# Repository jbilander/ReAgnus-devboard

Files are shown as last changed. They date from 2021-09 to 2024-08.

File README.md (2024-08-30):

# ReAgnus-devboard
A development board for ReAgnus<br />

Compatible with the [PLCC-84-plug](https://github.com/jbilander/PLCC-84-plug)

With this board you can signal tap a real Agnus chip by having a real Agnus IC in one socket and ReAgnus in the other.

***

REV 1C

<a href="images/ReAgnus-devboard_pic1.jpg">
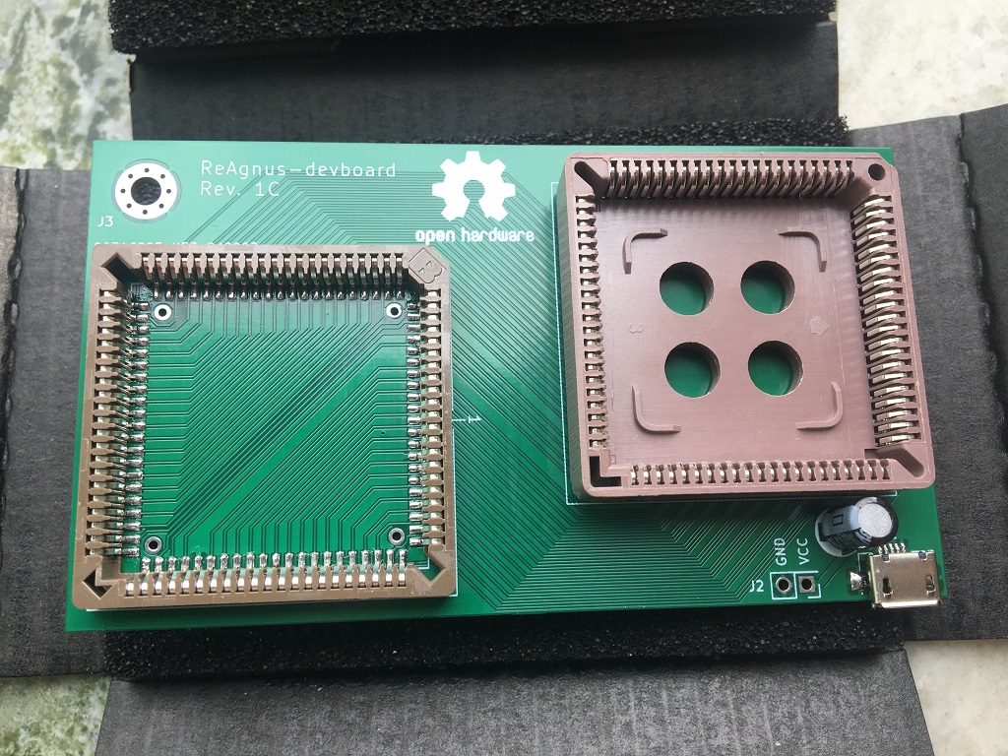
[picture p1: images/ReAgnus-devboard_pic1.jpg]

</a>
<br />
<a href="images/ReAgnus-devboard_pic2.jpg">
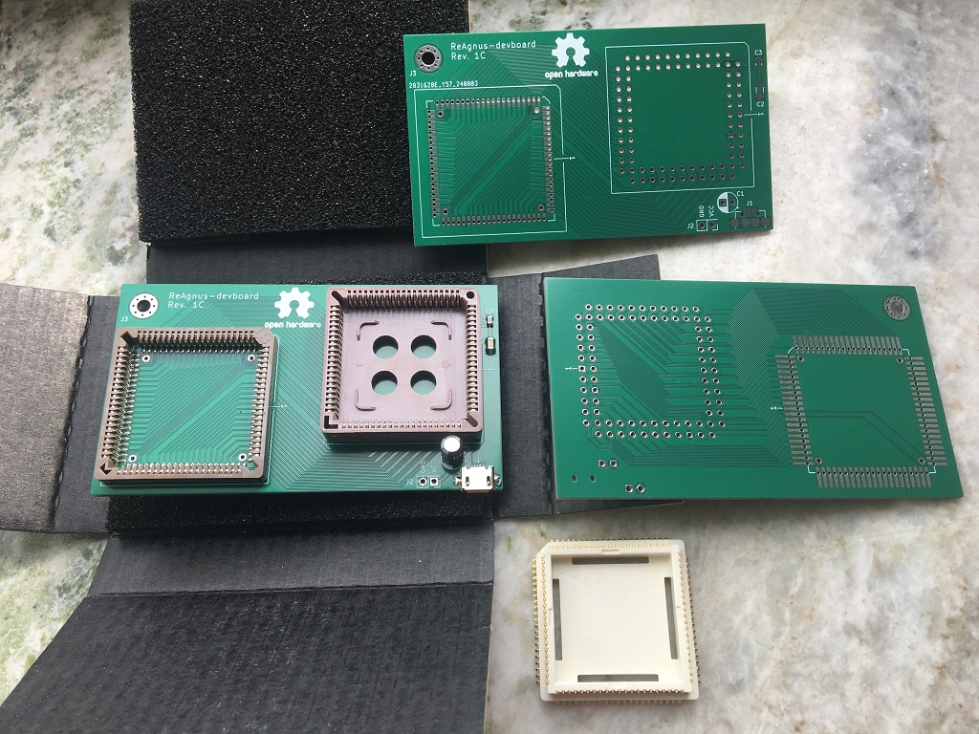
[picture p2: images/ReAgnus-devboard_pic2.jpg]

</a>
<br />
<a href="images/ReAgnus-devboard_pic3.jpg">
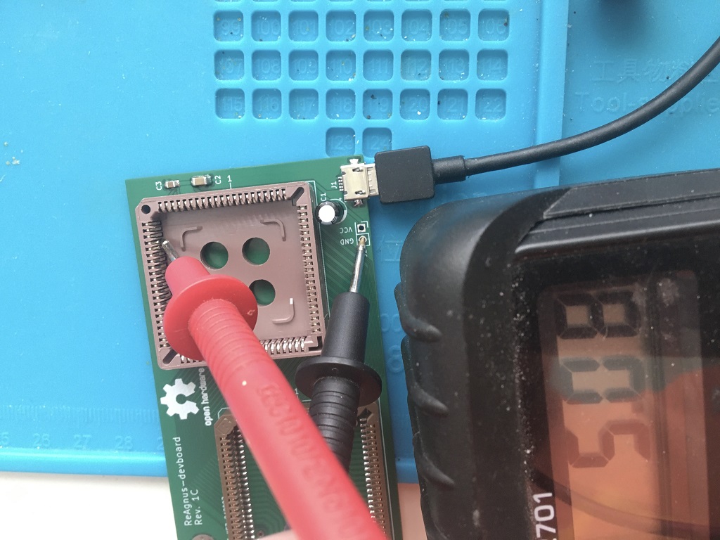
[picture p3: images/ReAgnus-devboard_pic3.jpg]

</a>
<br />
<a href="images/ReAgnus-devboard_pic4.jpg">
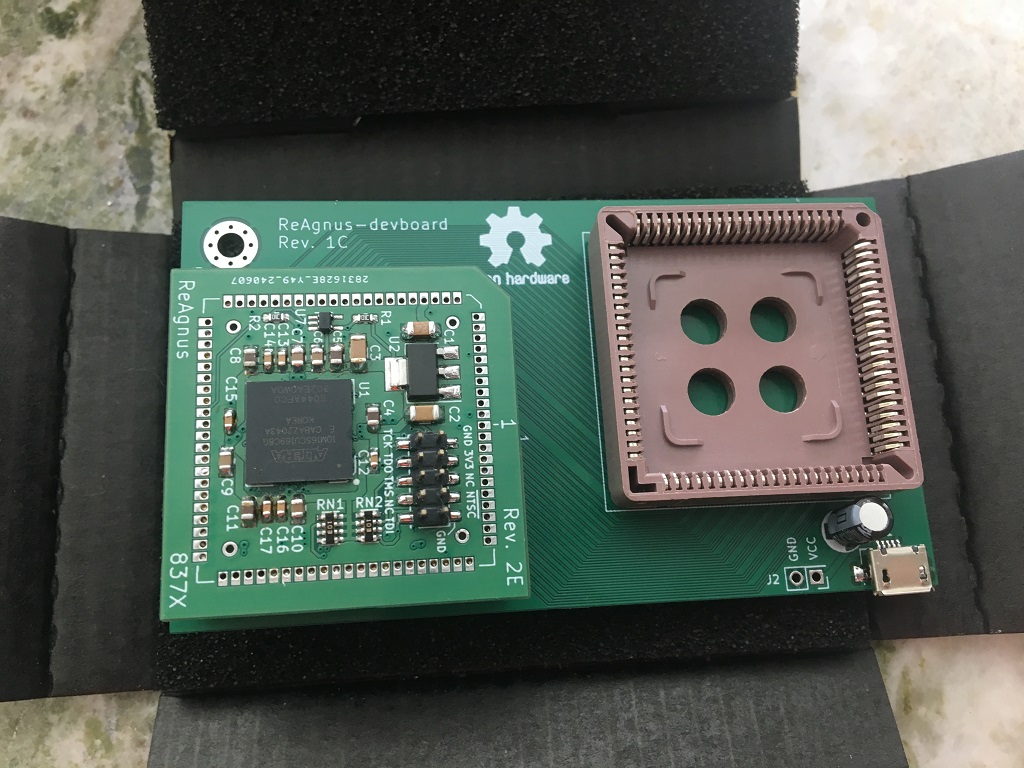
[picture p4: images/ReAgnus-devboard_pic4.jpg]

</a>
<br />
<a href="images/ReAgnus-devboard_pic5.jpg">
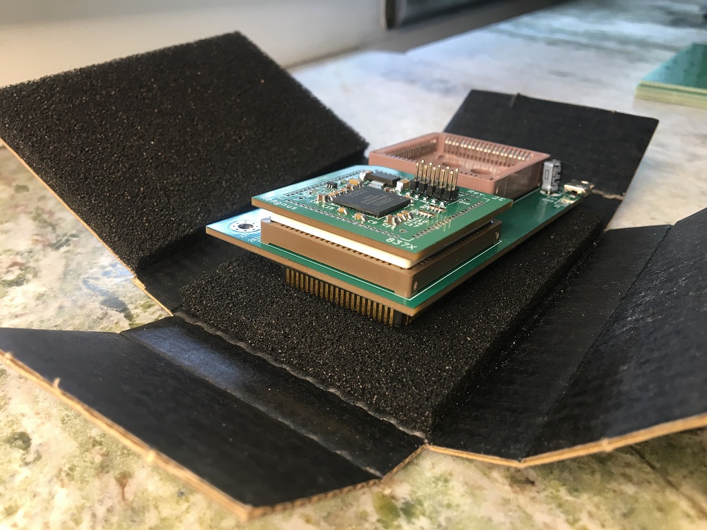
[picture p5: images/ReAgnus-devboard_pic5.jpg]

</a>

***

[][cc-by-sa]

This work is licensed under a
[Creative Commons Attribution-ShareAlike 4.0 International License][cc-by-sa].

[][cc-by-sa]

[cc-by-sa]: http://creativecommons.org/licenses/by-sa/4.0/
[cc-by-sa-image]: https://licensebuttons.net/l/by-sa/4.0/88x31.png
[cc-by-sa-shield]: https://img.shields.io/badge/License-CC%20BY--SA%204.0-lightgrey.svg

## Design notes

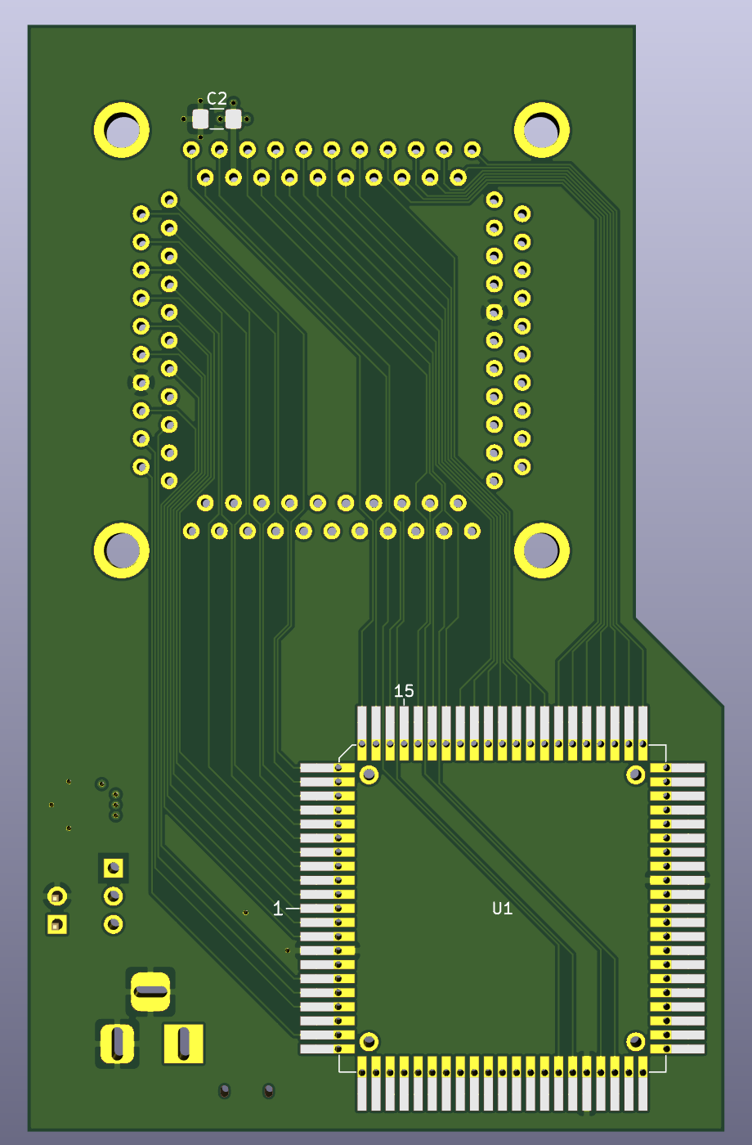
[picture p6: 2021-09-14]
images/ReAgnus-devboard_pic2.png

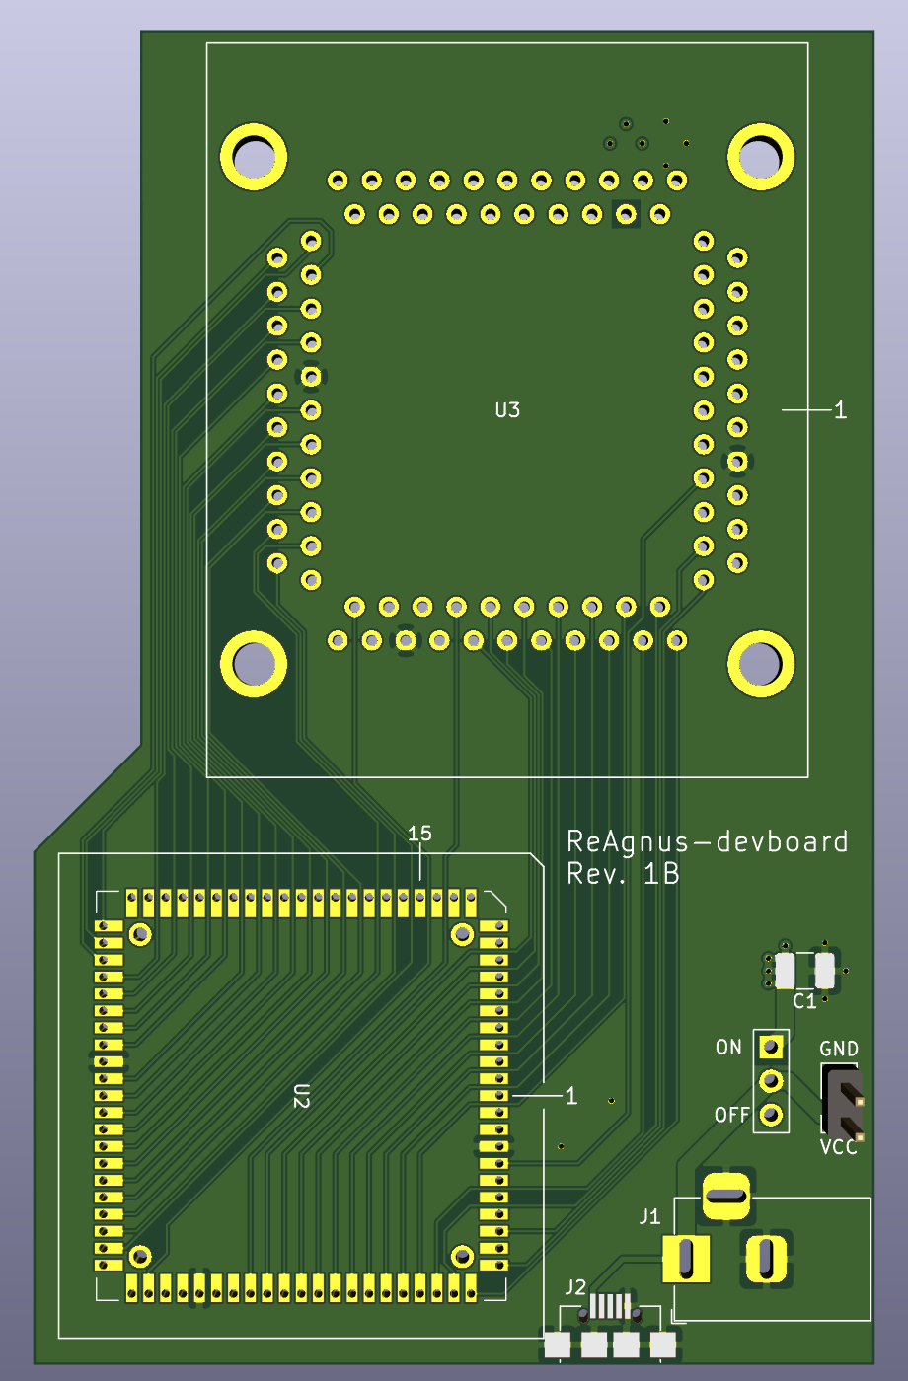
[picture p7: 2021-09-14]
images/ReAgnus-devboard_pic1.png

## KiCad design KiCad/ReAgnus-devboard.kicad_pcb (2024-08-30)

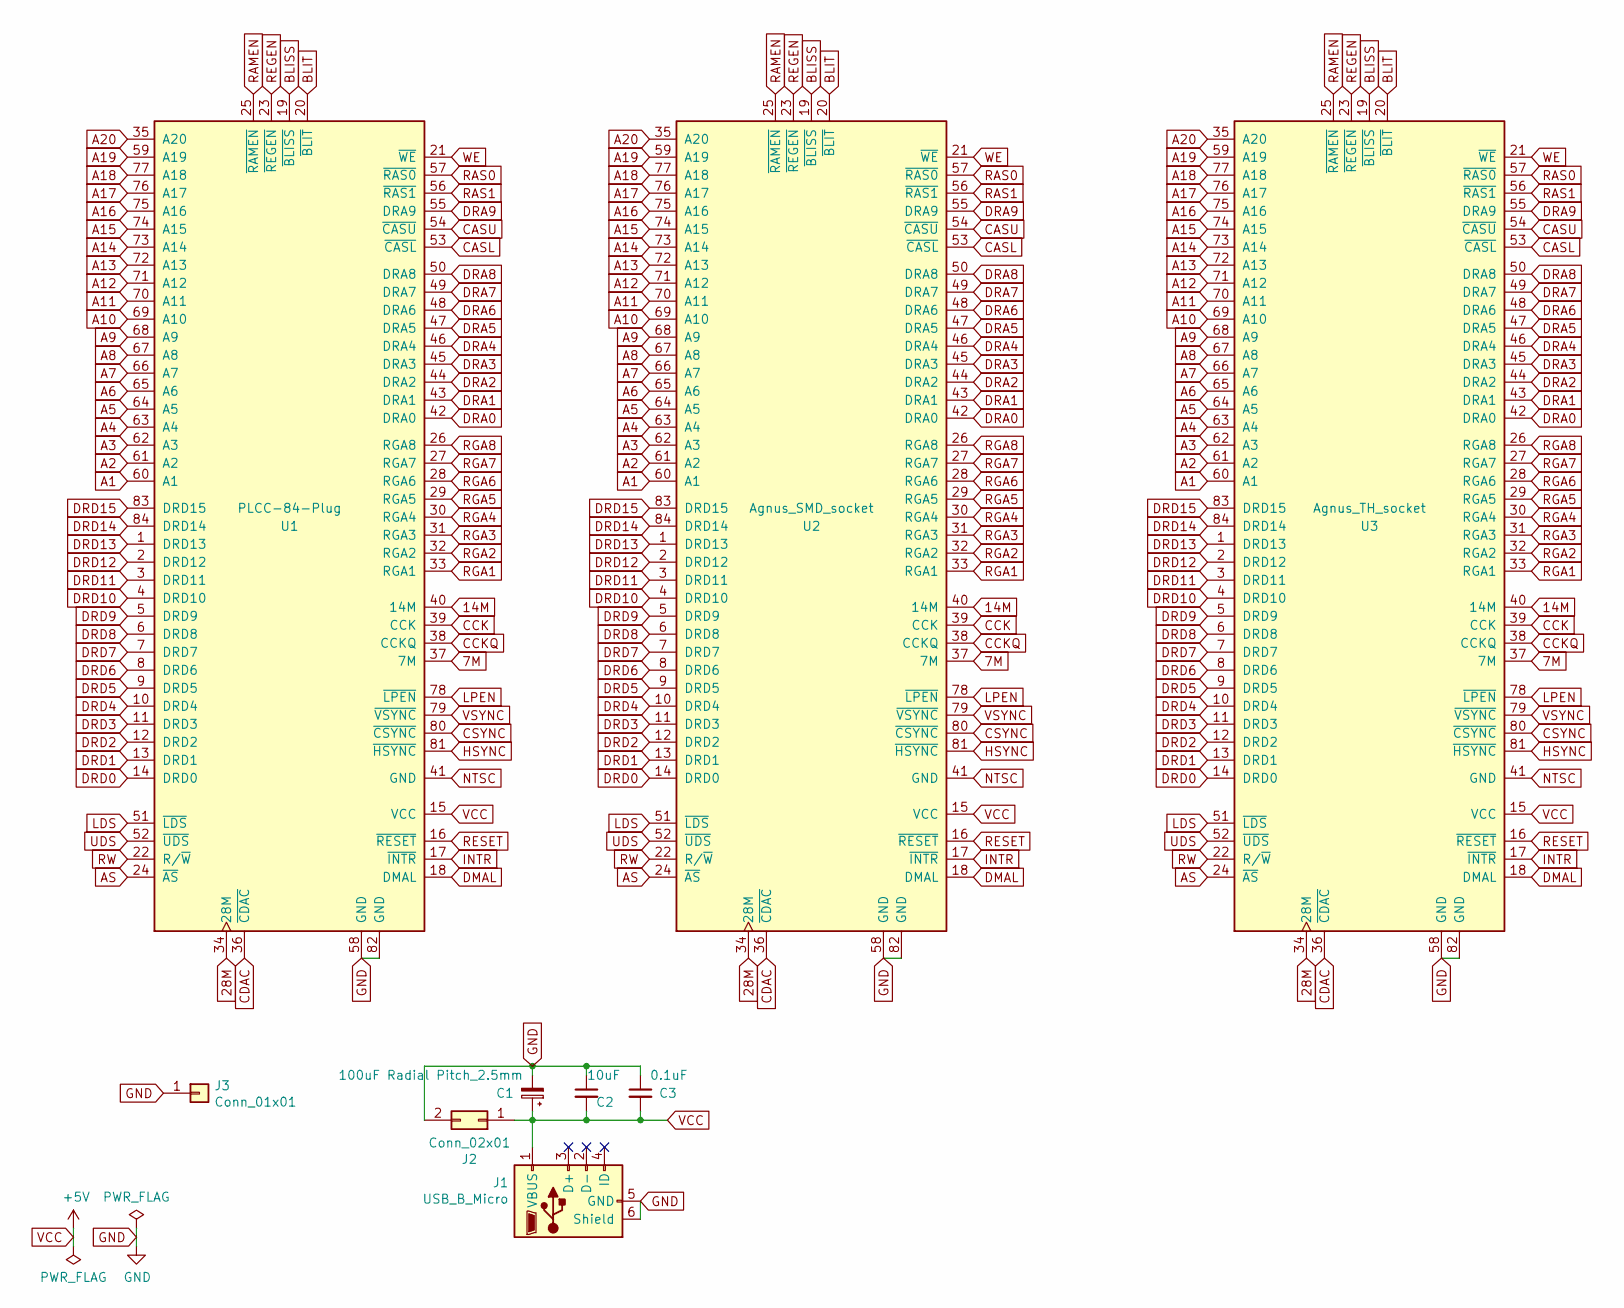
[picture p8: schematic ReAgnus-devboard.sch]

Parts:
C1: 100uF Radial Pitch_2.5mm; CP_Radial_D5.0mm_P2.50mm
C2: 10uF; C_1206_3216Metric_Pad1.33x1.80mm_HandSolder
C3: 0.1uF; C_0805_2012Metric_Pad1.18x1.45mm_HandSolder
J1: USB_B_Micro; USB_Micro-B_Unknown_5s_SMT
J2: Conn_02x01; PinHeader_2x01_P2.54mm_Vertical
J3: Conn_01x01; MountingHole_3.2mm_M3_Pad_Via
U1: PLCC-84-Plug; PLCC-84_Plug_P1.27mm_mirrored
U2: Agnus_SMD_socket; PLCC-84_SMD-Socket_TH_modded
U3: Agnus_TH_socket; PLCC-84_THT-Socket

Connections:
7M: U1.37 (7M), U2.37 (7M), U3.37 (7M)
14M: U1.40 (14M), U2.40 (14M), U3.40 (14M)
28M: U1.34 (28M), U2.34 (28M), U3.34 (28M)
A1: U1.60 (A1), U2.60 (A1), U3.60 (A1)
A2: U1.61 (A2), U2.61 (A2), U3.61 (A2)
A3: U1.62 (A3), U2.62 (A3), U3.62 (A3)
A4: U1.63 (A4), U2.63 (A4), U3.63 (A4)
A5: U1.64 (A5), U2.64 (A5), U3.64 (A5)
A6: U1.65 (A6), U2.65 (A6), U3.65 (A6)
A7: U1.66 (A7), U2.66 (A7), U3.66 (A7)
A8: U1.67 (A8), U2.67 (A8), U3.67 (A8)
A9: U1.68 (A9), U2.68 (A9), U3.68 (A9)
A10: U1.69 (A10), U2.69 (A10), U3.69 (A10)
A11: U1.70 (A11), U2.70 (A11), U3.70 (A11)
A12: U1.71 (A12), U2.71 (A12), U3.71 (A12)
A13: U1.72 (A13), U2.72 (A13), U3.72 (A13)
A14: U1.73 (A14), U2.73 (A14), U3.73 (A14)
A15: U1.74 (A15), U2.74 (A15), U3.74 (A15)
A16: U1.75 (A16), U2.75 (A16), U3.75 (A16)
A17: U1.76 (A17), U2.76 (A17), U3.76 (A17)
A18: U1.77 (A18), U2.77 (A18), U3.77 (A18)
A19: U1.59 (A19), U2.59 (A19), U3.59 (A19)
A20: U1.35 (A20), U2.35 (A20), U3.35 (A20)
AS: U1.24 (~AS), U2.24 (~AS), U3.24 (~AS)
BLISS: U1.19 (~BLISS), U2.19 (~BLISS), U3.19 (~BLISS)
BLIT: U1.20 (~BLIT), U2.20 (~BLIT), U3.20 (~BLIT)
CASL: U1.53 (~CASL), U2.53 (~CASL), U3.53 (~CASL)
CASU: U1.54 (~CASU), U2.54 (~CASU), U3.54 (~CASU)
CCK: U1.39 (CCK), U2.39 (CCK), U3.39 (CCK)
CCKQ: U1.38 (CCKQ), U2.38 (CCKQ), U3.38 (CCKQ)
CDAC: U1.36 (~CDAC), U2.36 (~CDAC), U3.36 (~CDAC)
CSYNC: U1.80 (~CSYNC), U2.80 (~CSYNC), U3.80 (~CSYNC)
DMAL: U1.18 (DMAL), U2.18 (DMAL), U3.18 (DMAL)
DRA0: U1.42 (DRA0), U2.42 (DRA0), U3.42 (DRA0)
DRA1: U1.43 (DRA1), U2.43 (DRA1), U3.43 (DRA1)
DRA2: U1.44 (DRA2), U2.44 (DRA2), U3.44 (DRA2)
DRA3: U1.45 (DRA3), U2.45 (DRA3), U3.45 (DRA3)
DRA4: U1.46 (DRA4), U2.46 (DRA4), U3.46 (DRA4)
DRA5: U1.47 (DRA5), U2.47 (DRA5), U3.47 (DRA5)
DRA6: U1.48 (DRA6), U2.48 (DRA6), U3.48 (DRA6)
DRA7: U1.49 (DRA7), U2.49 (DRA7), U3.49 (DRA7)
DRA8: U1.50 (DRA8), U2.50 (DRA8), U3.50 (DRA8)
DRA9: U1.55 (DRA9), U2.55 (DRA9), U3.55 (DRA9)
DRD0: U1.14 (DRD0), U2.14 (DRD0), U3.14 (DRD0)
DRD1: U1.13 (DRD1), U2.13 (DRD1), U3.13 (DRD1)
DRD2: U1.12 (DRD2), U2.12 (DRD2), U3.12 (DRD2)
DRD3: U1.11 (DRD3), U2.11 (DRD3), U3.11 (DRD3)
DRD4: U1.10 (DRD4), U2.10 (DRD4), U3.10 (DRD4)
DRD5: U1.9 (DRD5), U2.9 (DRD5), U3.9 (DRD5)
DRD6: U1.8 (DRD6), U2.8 (DRD6), U3.8 (DRD6)
DRD7: U1.7 (DRD7), U2.7 (DRD7), U3.7 (DRD7)
DRD8: U1.6 (DRD8), U2.6 (DRD8), U3.6 (DRD8)
DRD9: U1.5 (DRD9), U2.5 (DRD9), U3.5 (DRD9)
DRD10: U1.4 (DRD10), U2.4 (DRD10), U3.4 (DRD10)
DRD11: U1.3 (DRD11), U2.3 (DRD11), U3.3 (DRD11)
DRD12: U1.2 (DRD12), U2.2 (DRD12), U3.2 (DRD12)
DRD13: U1.1 (DRD13), U2.1 (DRD13), U3.1 (DRD13)
DRD14: U1.84 (DRD14), U2.84 (DRD14), U3.84 (DRD14)
DRD15: U1.83 (DRD15), U2.83 (DRD15), U3.83 (DRD15)
GND: C1.2, C2.1, C3.1, J1.5 (GND), J1.6 (Shield), J2.2, J3.1, U1.58 (GND), U1.82 (GND), U2.58 (GND), U2.82 (GND), U3.58 (GND), U3.82 (GND)
HSYNC: U1.81 (~HSYNC), U2.81 (~HSYNC), U3.81 (~HSYNC)
INTR: U1.17 (~INTR), U2.17 (~INTR), U3.17 (~INTR)
LDS: U1.51 (~LDS), U2.51 (~LDS), U3.51 (~LDS)
LPEN: U1.78 (~LPEN), U2.78 (~LPEN), U3.78 (~LPEN)
NTSC: U1.41 (GND), U2.41 (GND), U3.41 (GND)
RAMEN: U1.25 (~RAMEN), U2.25 (~RAMEN), U3.25 (~RAMEN)
RAS0: U1.57 (~RAS0), U2.57 (~RAS0), U3.57 (~RAS0)
RAS1: U1.56 (~RAS1), U2.56 (~RAS1), U3.56 (~RAS1)
REGEN: U1.23 (~REGEN), U2.23 (~REGEN), U3.23 (~REGEN)
RESET: U1.16 (~RESET), U2.16 (~RESET), U3.16 (~RESET)
RGA1: U1.33 (RGA1), U2.33 (RGA1), U3.33 (RGA1)
RGA2: U1.32 (RGA2), U2.32 (RGA2), U3.32 (RGA2)
RGA3: U1.31 (RGA3), U2.31 (RGA3), U3.31 (RGA3)
RGA4: U1.30 (RGA4), U2.30 (RGA4), U3.30 (RGA4)
RGA5: U1.29 (RGA5), U2.29 (RGA5), U3.29 (RGA5)
RGA6: U1.28 (RGA6), U2.28 (RGA6), U3.28 (RGA6)
RGA7: U1.27 (RGA7), U2.27 (RGA7), U3.27 (RGA7)
RGA8: U1.26 (RGA8), U2.26 (RGA8), U3.26 (RGA8)
RW: U1.22 (R/~W), U2.22 (R/~W), U3.22 (R/~W)
UDS: U1.52 (~UDS), U2.52 (~UDS), U3.52 (~UDS)
VCC: C1.1, C2.2, C3.2, J1.1 (VBUS), J2.1, U1.15 (VCC), U2.15 (VCC), U3.15 (VCC)
VSYNC: U1.79 (~VSYNC), U2.79 (~VSYNC), U3.79 (~VSYNC)
WE: U1.21 (~WE), U2.21 (~WE), U3.21 (~WE)

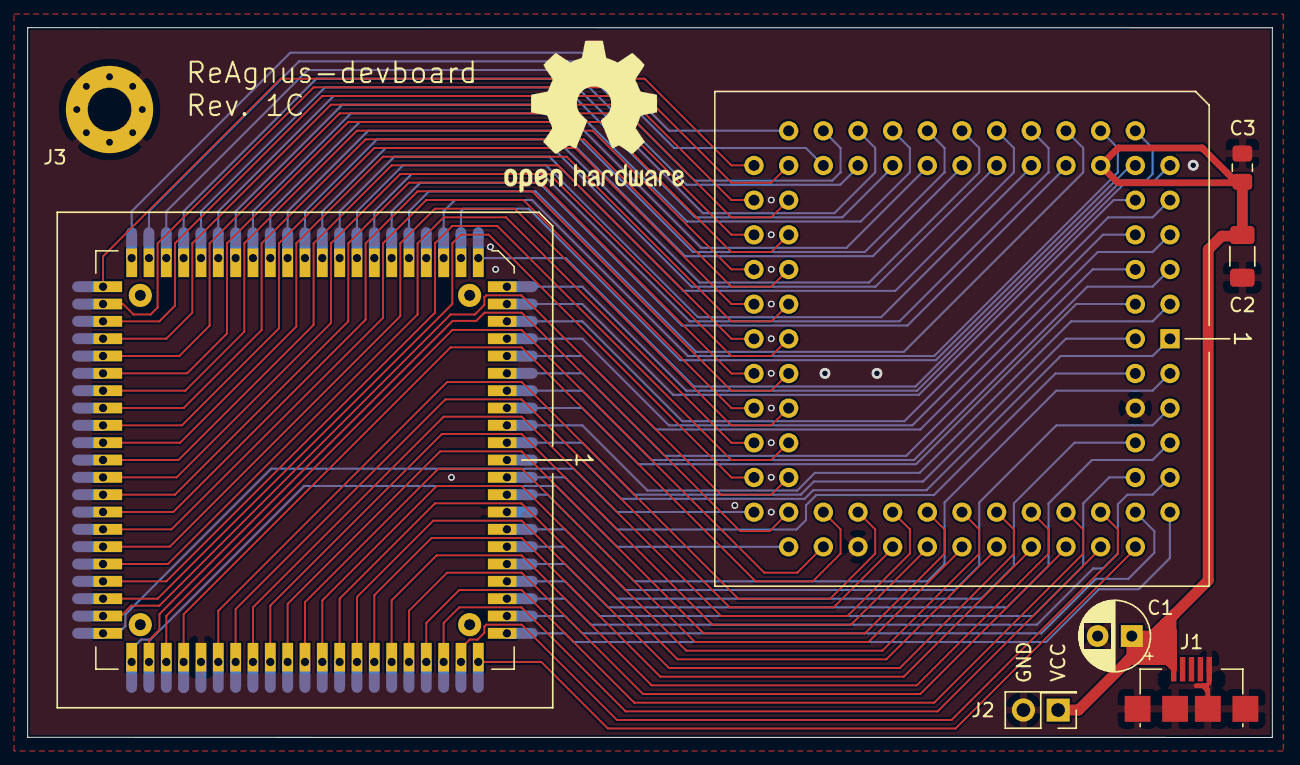
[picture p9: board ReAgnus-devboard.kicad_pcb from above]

Board: 4 copper layers, 91.2 x 52.0 mm, 9 parts (1 on the bottom side), 83 nets.

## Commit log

2021-06-24 added KiCad files
    [ReAgnus-devboard.kicad_pcb, ReAgnus-devboard.sch]
2021-06-29 added power jacks, rerouted with 6 mil tracks
    [ReAgnus-devboard.kicad_pcb, ReAgnus-devboard.sch]
2021-07-18 Removed unnecessary folder
    [ReAgnus-devboard.kicad_pcb, ReAgnus-devboard.sch]
2021-08-01 Resized footprint somewhat to better fit with homebrew PLCC-84-plug support PCB using TH-pins
    [ReAgnus-devboard.kicad_pcb]
2021-09-08 Added a microUSB jack for power supply
    [ReAgnus-devboard.kicad_pcb, ReAgnus-devboard.sch]
2021-09-14 Changed to 0.6mm holes, the spacing between hole and trace was less than 0.254mm, which is out of production capability
    [ReAgnus-devboard.kicad_pcb]
2024-08-30 nuke old design
    [ReAgnus-devboard.kicad_pcb, ReAgnus-devboard.sch]
2024-08-30 Add new design
    [ReAgnus-devboard.kicad_pcb, ReAgnus-devboard.sch]
2024-08-30 Update file
    [ReAgnus-devboard.kicad_pcb]

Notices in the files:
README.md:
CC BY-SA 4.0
